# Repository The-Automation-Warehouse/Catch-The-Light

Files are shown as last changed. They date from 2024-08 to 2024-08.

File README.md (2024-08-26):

# Catch-The-Light

Made as part of Arcade Hack Club

Used github copilot when writing code and readme.

https://github.com/user-attachments/assets/25a0203d-37ab-4f56-9c1b-5fb8322b415e

Inspired by the arcade game [Speed Demon](https://www.arcade-museum.com/Arcade/speed-demon) I wanted to make crude version of it using a circular LED matrix I found ounline.

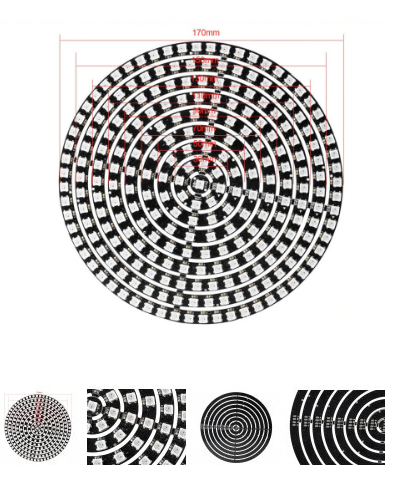
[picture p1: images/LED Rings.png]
Circular LED matrix


## Hardware

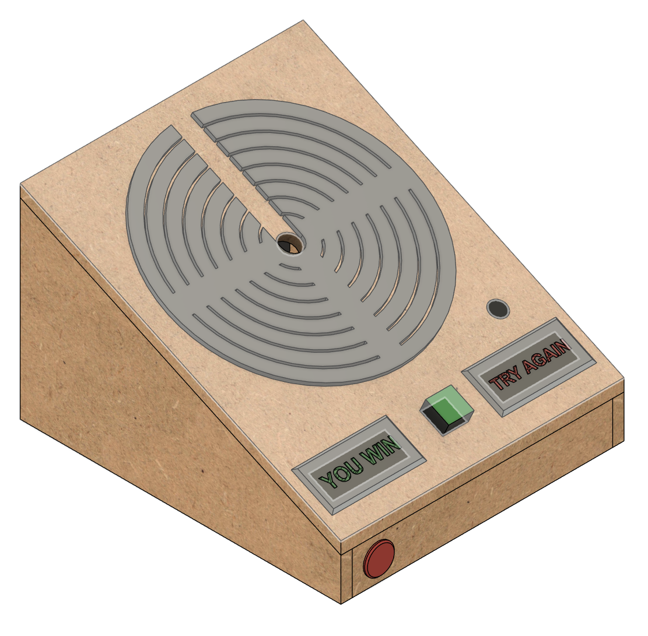
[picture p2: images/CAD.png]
CAD


I made a base out of 8mm MDF and used a 3D printed spacer to hold the LED rings.
This was not a very good design as MDF had a tendency to split and my paint job was not the best.

The stop button is a random button I found in my parts bin.
I also made two custom backlit signs for the game: green "YOU WIN" and red "TRY AGAIN".

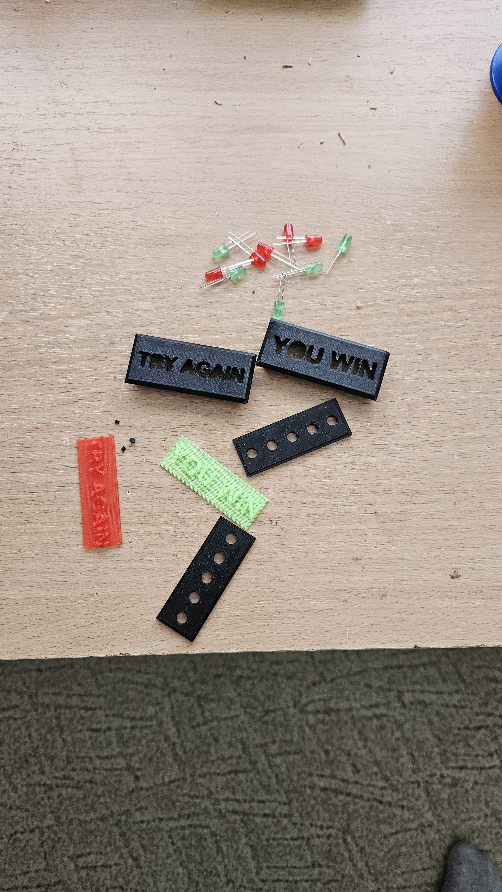
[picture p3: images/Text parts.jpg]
Text parts


The signs were printed in multiple parts and glued together (there is no need for a multi material printer).

A piezo buzzer is used for sound effects throughout the game.

The whole build is powered by a 5V 3A meanwell power supply with a switch mounted in the front and a C13 power socket in the back.

The brains of the operation is an arduino nano clone on piece of perfboard.

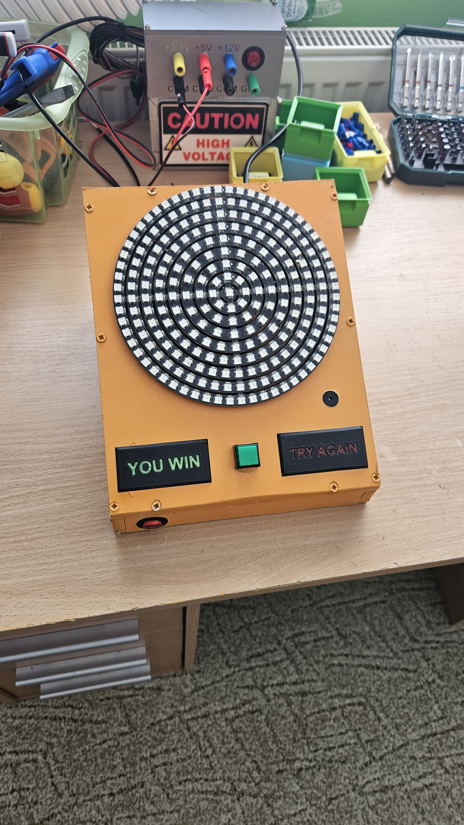
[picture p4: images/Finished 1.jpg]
Finished project image

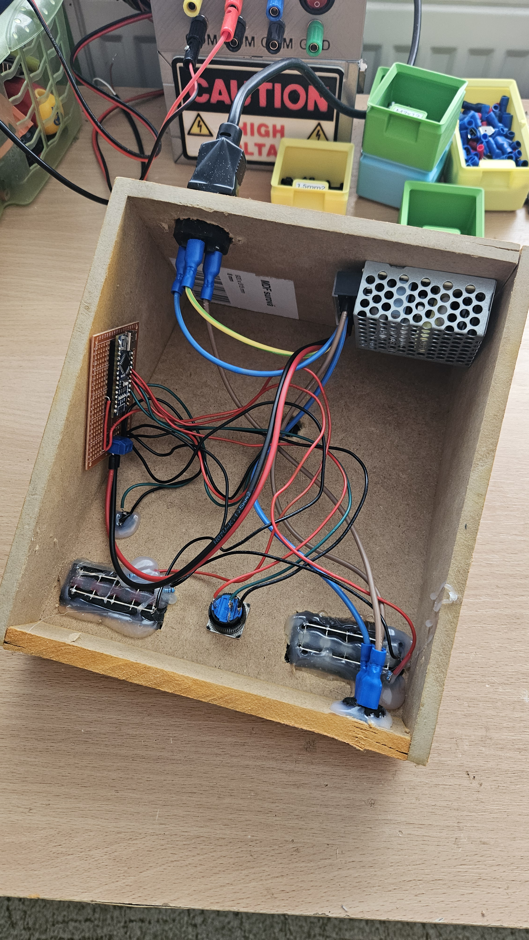
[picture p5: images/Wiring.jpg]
Wiring


## Shematic

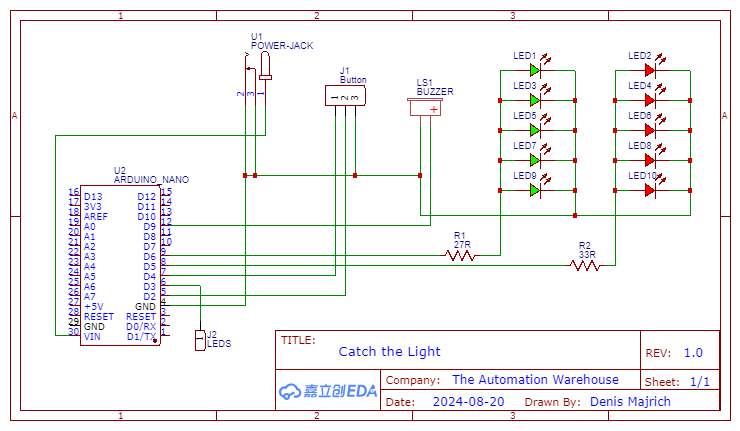
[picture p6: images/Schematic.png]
Schematic


## Code

The game starts with the player selecting of 3 difficulty levels, which changes how many LEDs are lit as the target (5, 4 or 3).
A light will start moving around the ring and the player has to press the button when the light is on any of the target LEDs.
If the player fails an animation will play and the game will restart.
If the player succeeds, the light will be able to move to the next ring and the target will change.
If the player reaches the last ring, an animation will play and the game will restart.

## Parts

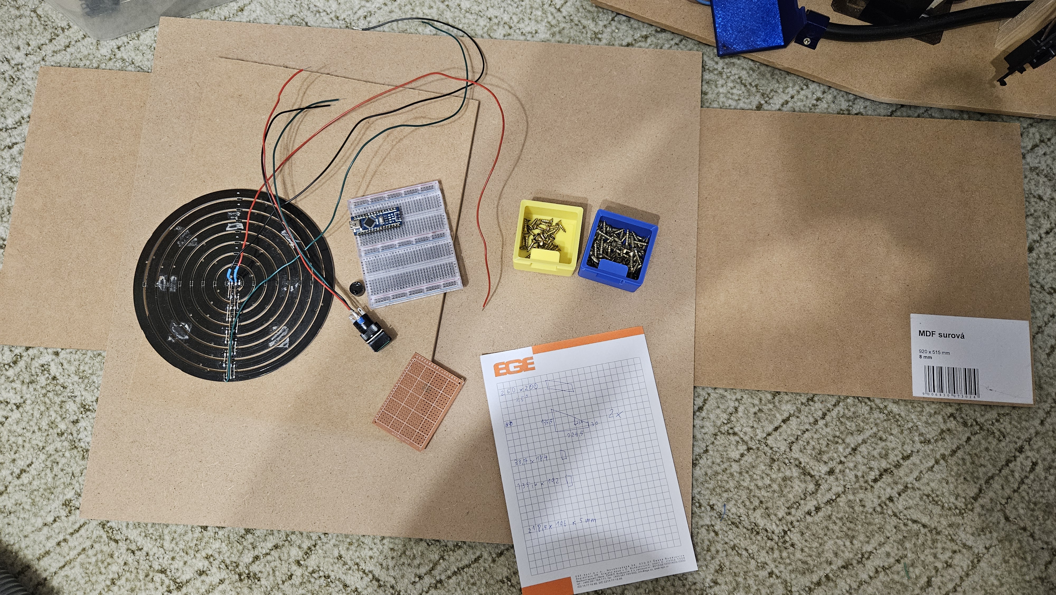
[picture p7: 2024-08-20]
making of/Parts.jpg

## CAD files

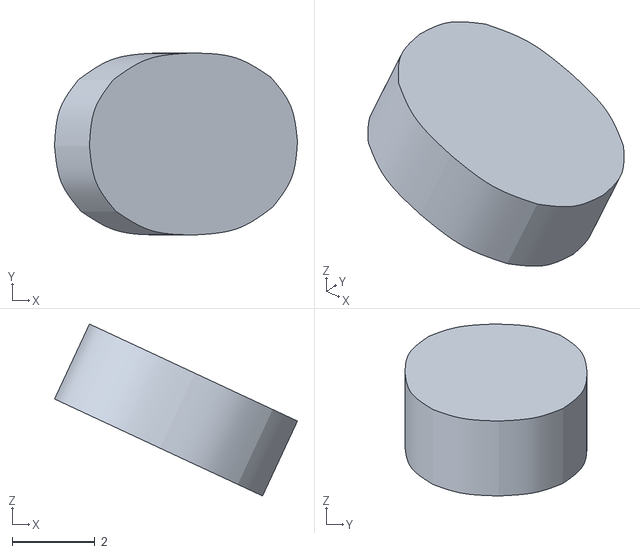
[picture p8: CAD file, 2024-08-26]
CAD/You Win - O.stl
5.88 x 4.40 x 4.16

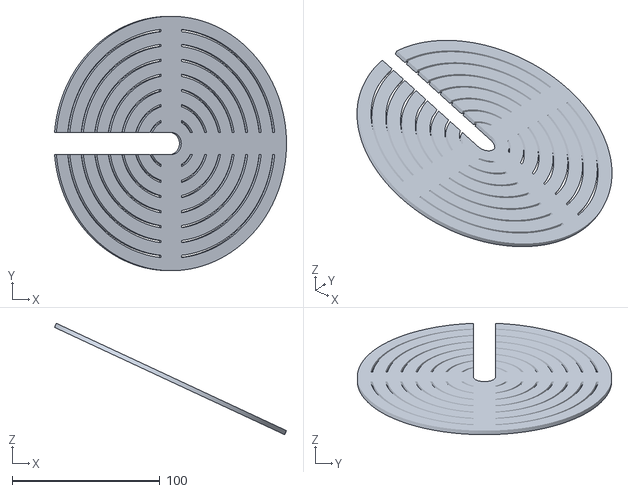
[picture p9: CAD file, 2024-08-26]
CAD/LED Rings Spacer.stl
156.8 x 172.0 x 75.3

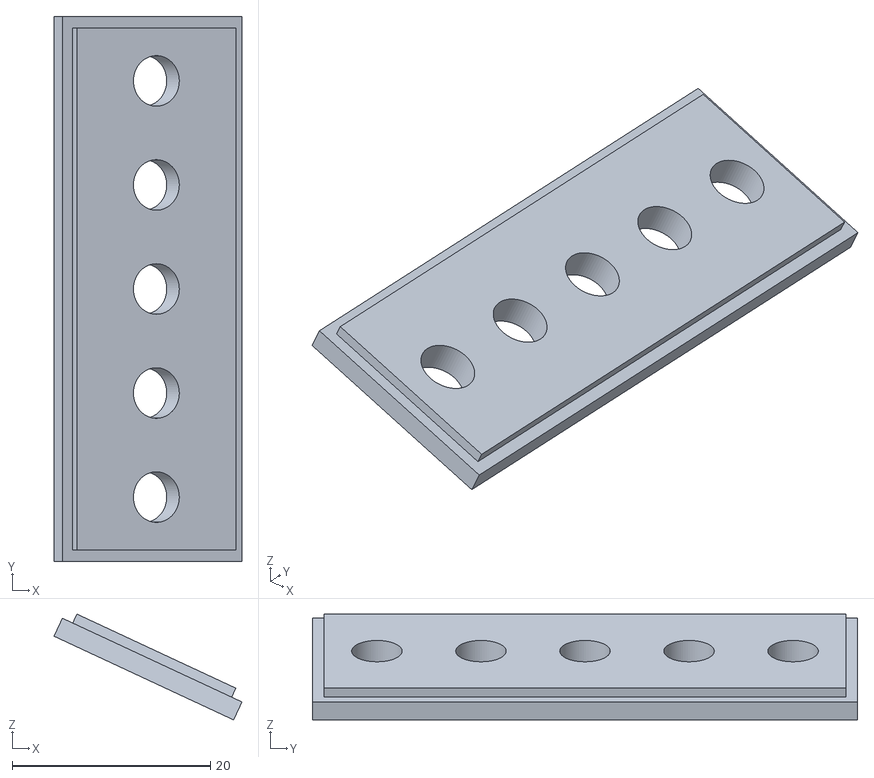
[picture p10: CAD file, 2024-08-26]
CAD/Try again - LED Holder.stl
19.0 x 55.0 x 10.7

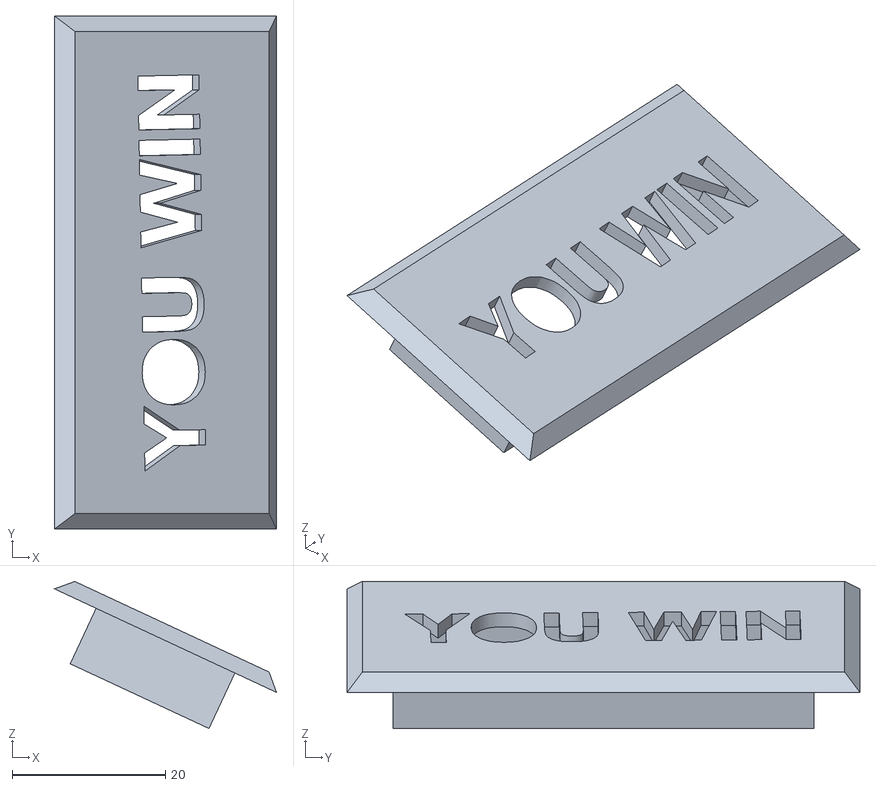
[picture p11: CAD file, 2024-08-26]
CAD/You Win - Cover.stl
29.0 x 67.0 x 19.2

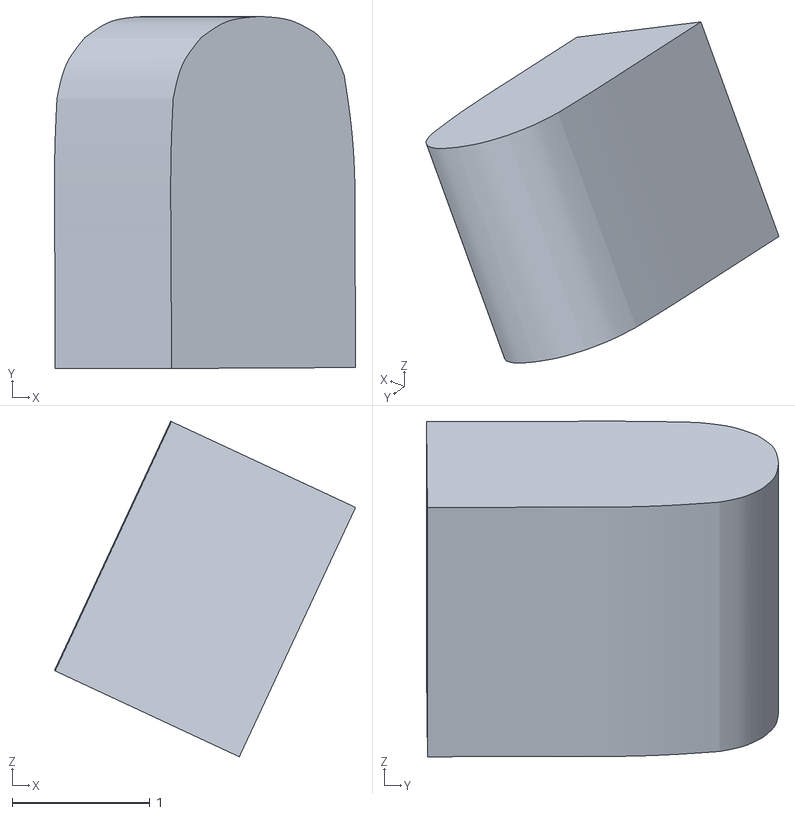
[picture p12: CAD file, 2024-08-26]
CAD/Try again - R.stl
2.19 x 2.56 x 2.44

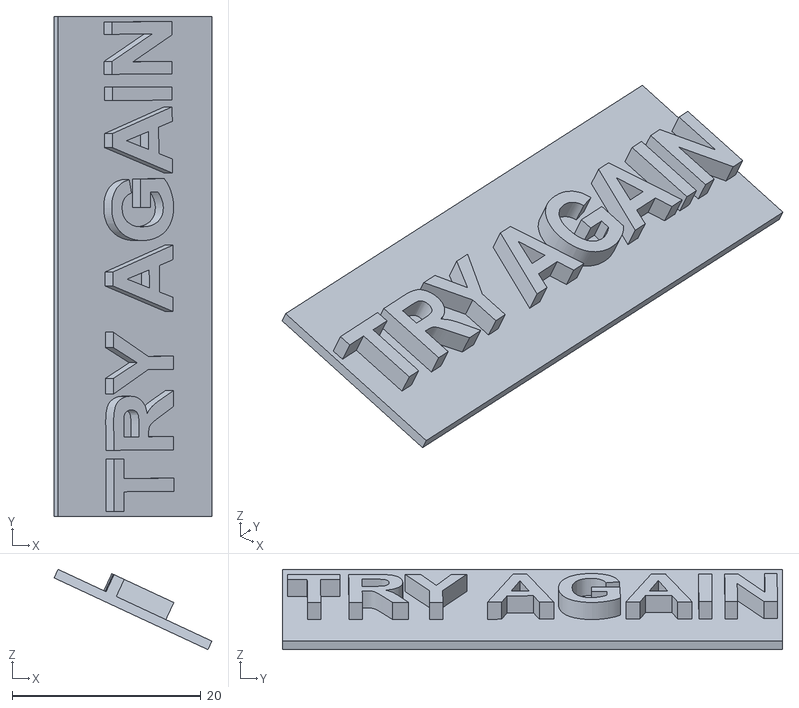
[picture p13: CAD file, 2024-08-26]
CAD/Try again - Text.stl
16.7 x 53.0 x 8.51

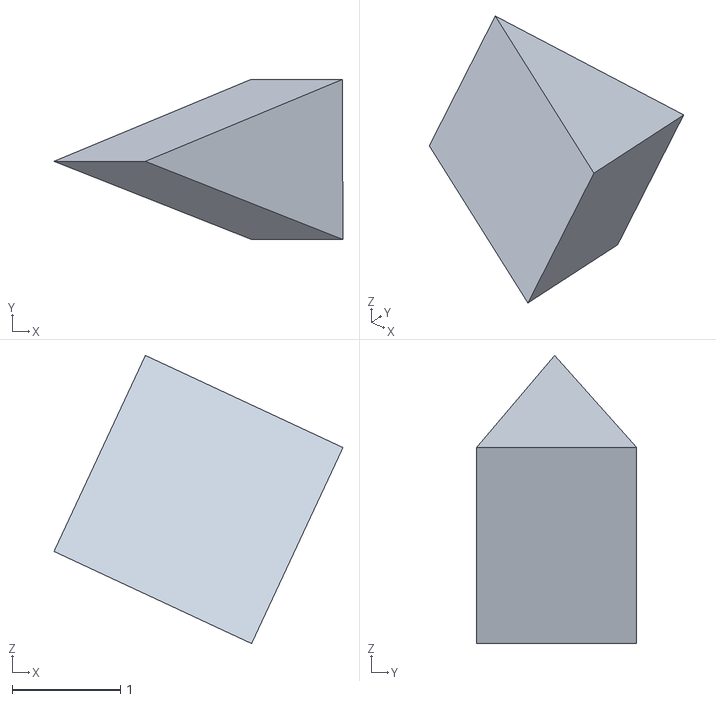
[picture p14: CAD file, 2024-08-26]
CAD/2x Try Again - A.stl
2.67 x 1.48 x 2.66

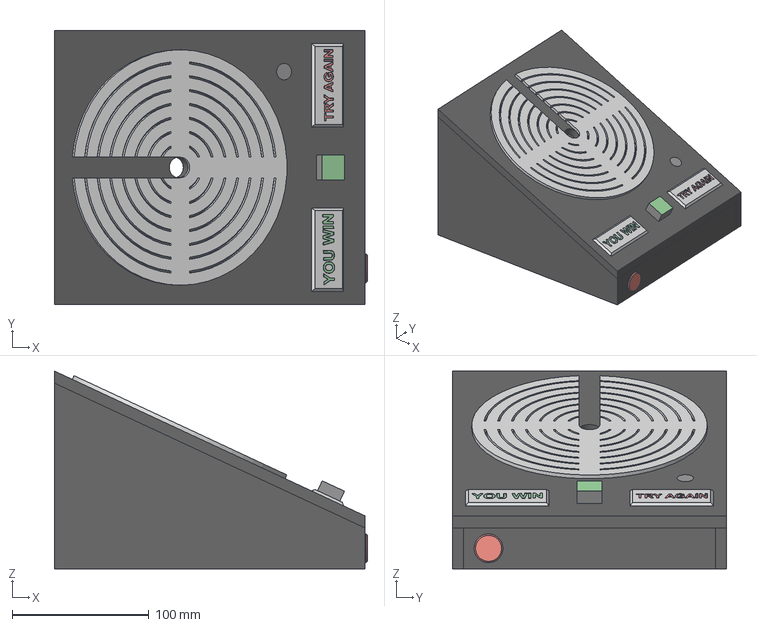
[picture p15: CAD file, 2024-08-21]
CAD/Catch The Light.step
228.6 x 200.0 x 144.5 mm

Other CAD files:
CAD/You Win - LED Holder.stl
CAD/You Win - Text.stl
CAD/Try again - Case.stl
CAD/Catch The Light.3mf
CAD/Catch The Light.f3d

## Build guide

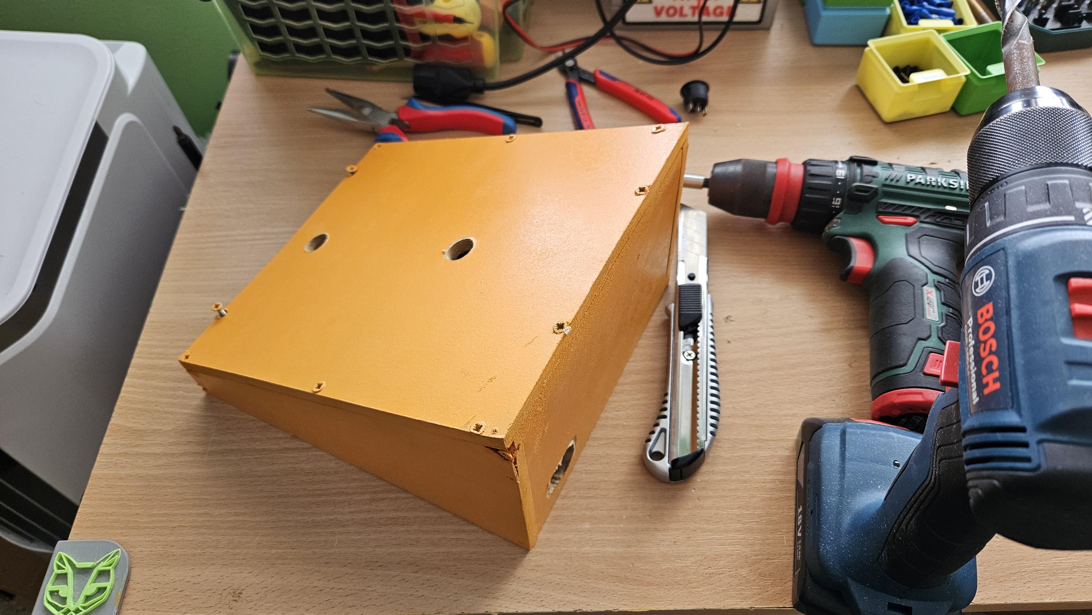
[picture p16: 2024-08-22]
making of/Holes.jpg

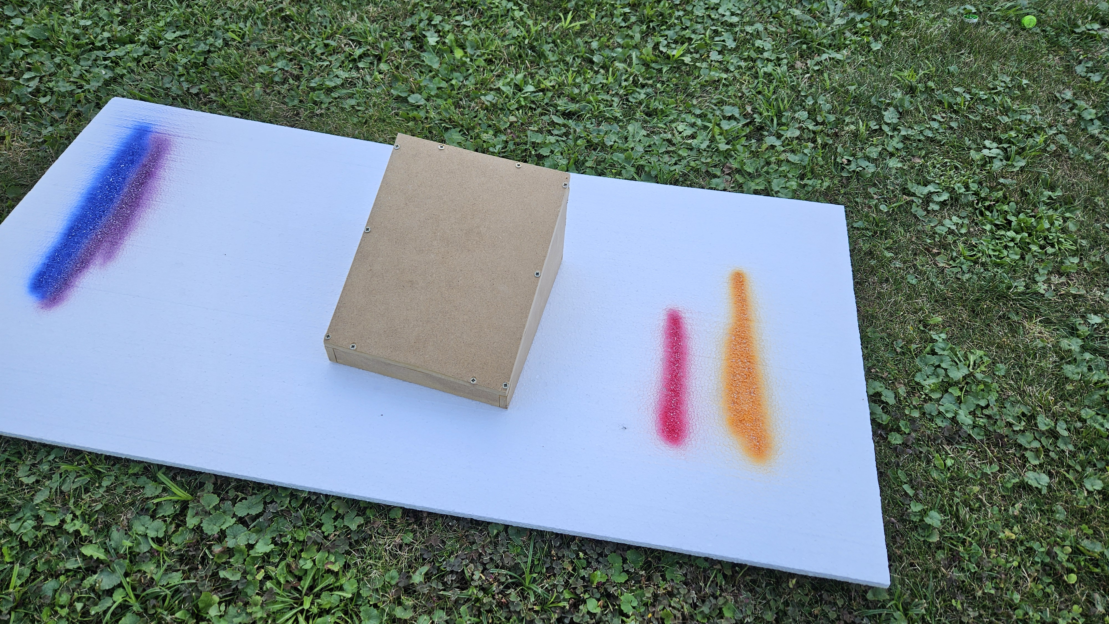
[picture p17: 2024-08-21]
making of/Woodworking 2.jpg

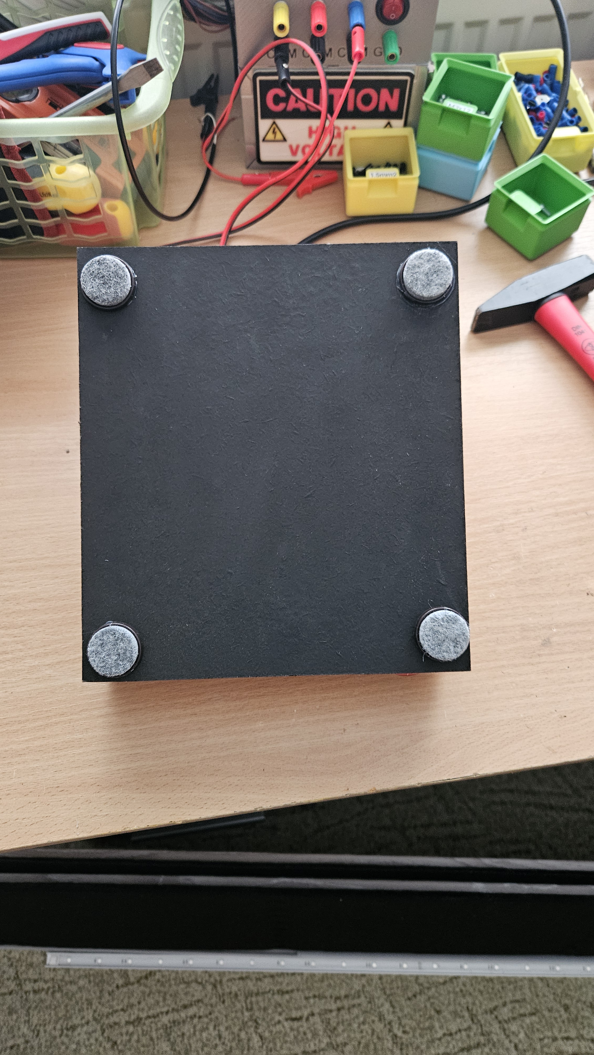
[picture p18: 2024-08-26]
making of/Feet 2.jpg

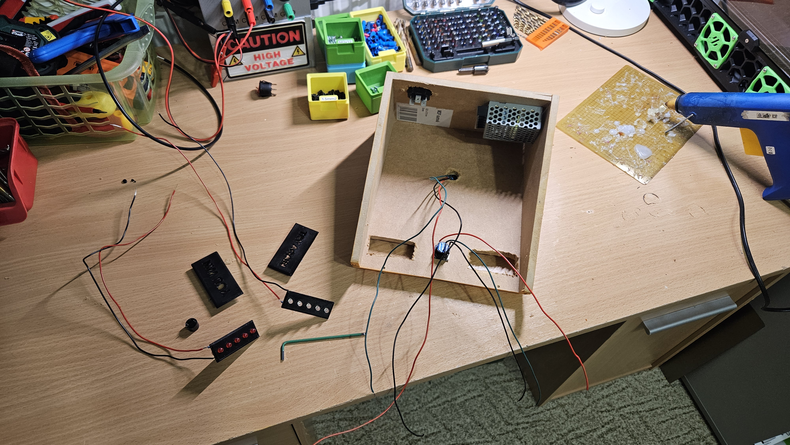
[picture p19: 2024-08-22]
making of/PSU mounted.jpg

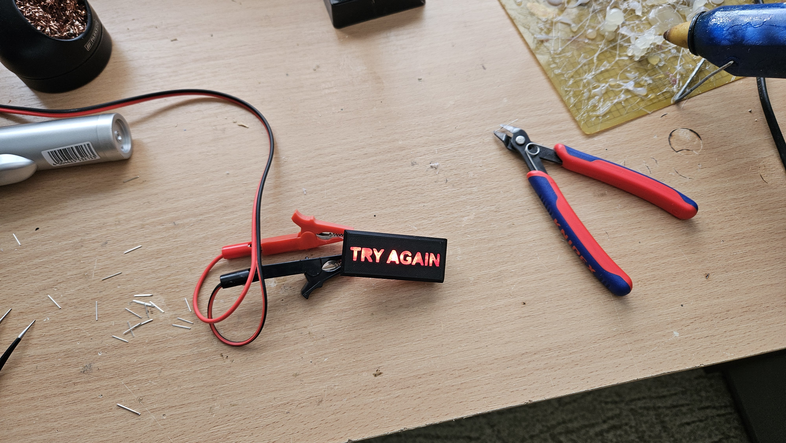
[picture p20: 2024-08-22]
making of/Text front.jpg

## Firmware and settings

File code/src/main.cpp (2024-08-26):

/*
 * Catch-The-Light
 * This is a crude arcade game inspired by "Speed Demon".
  * It consists of a ring of LEDs through which a light travels.
  * In each round, the light travels through the ring and the player has to press a button at the right time to stop the light.
  * The difficulty of the game changes the number of target LEDs that light up in each ring.
  * If the player presses the button at the right time, the light progresses to the next round and the next ring of LEDs lights up.
  * If the player presses the button at the wrong time, the game is over.
  * The game is won when the light has traveled through all the rings.
  * There are two backlit signs that light up when the game is won or lost.
 */



#include <Arduino.h>
#include <FastLED.h>

#define BUTTON 2
#define LEDS_PIN 3
#define BUTTON_LED 4
#define BUZZER 9
#define WIN_LEDS 6
#define TRY_AGAIN_LEDS 5

// Ring 1 - 60 LEDs
// Ring 2 - 48 LEDs
// Ring 3 - 32 LEDs
// Ring 4 - 26 LEDs
// Ring 5 - 16 LEDs
// Ring 6 - 12 LEDs
// Ring 7 - 8 LEDs
// One LED in the middle

int ring0 = 60;
int ring1 = 48;
int ring2 = 40;
int ring3 = 32;
int ring4 = 24;
int ring5 = 16;
int ring6 = 12;
int ring7 = 8;
int middle = 1;
int rings[] = {ring0, ring1, ring2, ring3, ring4, ring5, ring6, ring7, middle};
#define NUM_RINGS 7
#define NUM_LEDS 241
CRGB leds[NUM_LEDS];

bool doInterrupt = false;

// Game variables
int currentRing = 0;
int currentLED = 0;
int stopLED = 0;
int targetLEDs[5] = {0, 0, 0, 0, 0};
int oldTargetLEDs[80] = {0}; // Stores the previous target LEDs so that they can be lit up again in the next rounds
int totalLEDs = 0;
bool nextRound = false;
bool gameWon = false;
bool gameOver = false;
// Easy - 1
// Medium - 2
// Hard - 3
int difficulty = 0;


void handleButton();
void selectDifficulty();
void fillRing(CRGB leds[], CRGB color, int ringSizes[], int ringIndex);
void playGame();

void setup() { 

  Serial.begin(115200);
  pinMode(BUTTON, INPUT_PULLUP);
  pinMode(BUTTON_LED, OUTPUT);
  pinMode(BUZZER, OUTPUT);
  pinMode(WIN_LEDS, OUTPUT);
  pinMode(TRY_AGAIN_LEDS, OUTPUT);
  digitalWrite(WIN_LEDS, HIGH);
  digitalWrite(TRY_AGAIN_LEDS, HIGH);
  digitalWrite(BUTTON_LED, LOW);
  digitalWrite(BUZZER, LOW);

  randomSeed(analogRead(A0));

  FastLED.addLeds<WS2812B, LEDS_PIN, GRB>(leds, NUM_LEDS);
  FastLED.setBrightness(20);


  // Beep 4 times
  for (int i = 0; i < 5; i++) {
    tone(BUZZER, 480, 100);
    delay(200);
  }

  for (int i = 0; i < NUM_LEDS; i++) {
    fadeToBlackBy(leds, NUM_LEDS, 10);
    leds[i] = CRGB::Cyan;
    FastLED.show();
    delay(6);
  }

  digitalWrite(WIN_LEDS, LOW);
  digitalWrite(TRY_AGAIN_LEDS, LOW);

}





void loop() { 

  

  selectDifficulty();
  Serial.println("Difficulty selected: ");
  Serial.println(difficulty);
  playGame();


}






void handleButton() {

  if (doInterrupt) {
    stopLED = currentLED;
    // Check if the button is pressed at the right time (the stopLED is any of the targetLEDs)
    if (stopLED == targetLEDs[0] || stopLED == targetLEDs[1] || stopLED == targetLEDs[2] || stopLED == targetLEDs[3] || stopLED == targetLEDs[4]) {
      // If the button is pressed at the right time, the light progresses to the next ring
      if (currentRing == NUM_RINGS) {
        Serial.println("Game won!");
        gameOver = true;
        gameWon = true;
        doInterrupt = false;
      } else {
        currentRing++;
        nextRound = true;
        doInterrupt = false;
      }
    } else {
      // If the button is pressed at the wrong time, the game is over
      Serial.println("Game over!");
      gameOver = true;
      nextRound = true;
      doInterrupt = false;
    }
    Serial.print("Stopped at: ");
    Serial.println(stopLED);
  }

}








void selectDifficulty() {
  // The user can switch between the difficulty levels by pressing the button
  // The difficulty changes how many LEDs light up in each ring
  // By holding the button for 1 seconds, the user can confirm the selection
  
  // Easy - 1
  // Medium - 2
  // Hard - 3
  
  bool confirmSelection = false;
  bool changeDifficulty = false;
  difficulty = 1;
  unsigned long startMillis = millis(); // Store the start time
  const unsigned long timeout = 60000;  // 60 seconds timeout

  fill_solid(leds, NUM_LEDS, CRGB::Black);
  fillRing(leds, CRGB::Green, rings, 0);
  fillRing(leds, CRGB::Green, rings, 1);
  FastLED.show();

  digitalWrite(BUTTON_LED, HIGH);
  
  while (!confirmSelection && (millis() - startMillis < timeout)) {  // Add timeout condition
    if (digitalRead(BUTTON) == LOW) {
      delay(50); // Debounce delay
      if (digitalRead(BUTTON) == LOW) { // Check again after debounce delay
        unsigned long lastMillis = millis();
        // Check if the button is pressed for 1 second
        while (digitalRead(BUTTON) == LOW) {
          if (millis() - lastMillis > 1000) {
            confirmSelection = true;
            tone(BUZZER, 480, 400);
            break;
          }
        }
        if (!confirmSelection) {
          tone(BUZZER, 800, 100);
          changeDifficulty = true;
        }
      }
    }     
    
    if (changeDifficulty) {
      difficulty++;
      if (difficulty > 3) {
        difficulty = 1;
      }
      
      switch (difficulty) {
        case 1:
          fill_solid(leds, NUM_LEDS, CRGB::Black);
          fillRing(leds, CRGB::Green, rings, 0);
          fillRing(leds, CRGB::Green, rings, 1);
          FastLED.show();
          break;
        case 2:
          fill_solid(leds, NUM_LEDS, CRGB::Black);
          fillRing(leds, CRGB::Yellow, rings, 2);
          fillRing(leds, CRGB::Yellow, rings, 3);
          FastLED.show();
          break;
        case 3:
          fill_solid(leds, NUM_LEDS, CRGB::Black);
          fillRing(leds, CRGB::Red, rings, 4);
          fillRing(leds, CRGB::Red, rings, 5);
          FastLED.show();
          break;
      }
      changeDifficulty = false;
    }
  }

  digitalWrite(BUTTON_LED, LOW);
  fill_solid(leds, NUM_LEDS, CRGB::Black);
  delay(500);
  
  if (confirmSelection) {  // Only blink if selection is confirmed
    // Blink the corresponding ring to indicate the selected difficulty
    for (int i = 0; i < 3; i++) {
      switch (difficulty) {
        case 1:
          fillRing(leds, CRGB::Green, rings, 0);
          fillRing(leds, CRGB::Green, rings, 1);
          break;
        case 2:
          fillRing(leds, CRGB::Yellow, rings, 2);
          fillRing(leds, CRGB::Yellow, rings, 3);
          break;
        case 3:
          fillRing(leds, CRGB::Red, rings, 4);
          fillRing(leds, CRGB::Red, rings, 5);
          break;
      }
      FastLED.show();
      delay(200);
      fill_solid(leds, NUM_LEDS, CRGB::Black);
      FastLED.show();
      delay(200);
    }
  } else {
    // If the selection is not confirmed run the function again
    selectDifficulty();
  }
}

  






void fillRing(CRGB leds[], CRGB color, int ringSizes[], int ringIndex) {
    int tottalLeds = 0;
    for (int i = 0; i < ringIndex+1; i++) {
        tottalLeds += ringSizes[i];
    }
    
  for (int i = tottalLeds - ringSizes[ringIndex]; i < tottalLeds; i++) {
    leds[i] = color;
  }
}












  

void playGame() {
  while (!gameOver)
  {
    if (gameOver) {
      break;
    }
    Serial.print("Current ring: ");
    Serial.println(currentRing);
    totalLEDs = 0;
    currentLED = 0;
    FastLED.show();
    // Pick a random LED to light up as the target depending on the difficulty
    // Easy - 5 LED
    // Medium - 4 LEDs
    // Hard - 3 LEDs

resetTarget:

    for (int j = 0; j < currentRing; j++) {
      totalLEDs += rings[j];
    }
    targetLEDs[0] = random(totalLEDs, totalLEDs + rings[currentRing]);

    switch (difficulty) {
      case 1:
      {
        Serial.println("Easy");
        targetLEDs[1] = targetLEDs[0] + 1;
        targetLEDs[2] = targetLEDs[0] + 2;
        targetLEDs[3] = targetLEDs[0] - 1;
        targetLEDs[4] = targetLEDs[0] - 2;
      }
        break;
      case 2:
      {
        Serial.println("Medium");
        targetLEDs[1] = targetLEDs[0] + 1;
        targetLEDs[2] = targetLEDs[0] + 2;
        targetLEDs[3] = targetLEDs[0] - 1;
      }
        break; 
      case 3:
      {
        Serial.println("Hard");
        targetLEDs[1] = targetLEDs[0] + 1;
        targetLEDs[2] = targetLEDs[0] - 1;
      }
        break;
      }

      // Print the target LEDs
      Serial.print("Target LEDs: ");
      for (int j = 0; j < 5; j++) {
        Serial.print(targetLEDs[j]);
        Serial.print(" ");
      }
      Serial.println();

      // Print the old target LEDs
      Serial.print("Old target LEDs: ");
      for (int j = 0; j < 50; j++) {
        Serial.print(oldTargetLEDs[j]);
        Serial.print(" ");
      }
      Serial.println();
      // Check if the target LEDs are not out of bounds
      for (int j = 0; j < 5; j++) {
        if (targetLEDs[j] != 0) {
          if (targetLEDs[j] < totalLEDs || targetLEDs[j] + 1 > totalLEDs + rings[currentRing]) {
            for (int j = 0; j < 5; j++) {
              targetLEDs[j] = 0;
            }
            totalLEDs = 0;
            Serial.println("Target out of bounds");
            randomSeed(analogRead(A0));
            goto resetTarget;
          }
        }
      }


      // Light up the target LEDs
      for (int j = 0; j < 5; j++) {
        if (targetLEDs[j] != 0) {
          leds[targetLEDs[j]] = CHSV(64, 255, 128);
        }
      }
      FastLED.show();
      delay(30);
      attachInterrupt(digitalPinToInterrupt(BUTTON), handleButton, FALLING);
      delay(20);
      doInterrupt = true;
      while (!nextRound && !gameOver) {
        // Play the actual game

        // Adjust the fade speed depending on the current ring but cap it at 160
        fadeToBlackBy(leds, NUM_LEDS, min(160, (currentRing + 1) * 25));
        
        // Light up the target LEDs with 70% brightness yellow additevly
        for (int j = 0; j < 5; j++) {
          if (targetLEDs[j] != 0) {
            // Get the current color of the LED and add yellow to it
            leds[targetLEDs[j]] = blend(leds[targetLEDs[j]], CHSV(64, 255, 178), 128);
          }
        }
        // Light up the old target LEDs with 70% brightness red additevly
        for (unsigned int j = 0; j < sizeof(oldTargetLEDs) / sizeof(oldTargetLEDs[0]); j++) {
            if (oldTargetLEDs[j] != 0) {
              leds[oldTargetLEDs[j]] = blend(leds[oldTargetLEDs[j]], CHSV(0, 255, 178), 128);
            }
        }
        // Draw the moving light
        // Change the color of the light depending on the ring (if its in the current ring or not)
        if (currentLED < totalLEDs) {
          leds[currentLED] = CRGB::Green;
          tone(BUZZER, 32);
          delayMicroseconds(700);
          noTone(BUZZER);
          delay(6);
        } else {
          leds[currentLED] = CRGB::Blue;
          tone(BUZZER, 32);
          delayMicroseconds(1200);
          noTone(BUZZER);
          delay(28);
        }
        FastLED.show();
        
        currentLED++;

        if (currentLED == totalLEDs + rings[currentRing]) {
          currentLED = totalLEDs;
        }
      }
      // Bling the stopLED
      for (int i = 0; i < 3; i++) {
        if (stopLED == targetLEDs[0] || stopLED == targetLEDs[1] || stopLED == targetLEDs[2] || stopLED == targetLEDs[3] || stopLED == targetLEDs[4]) {
          leds[stopLED] = CRGB::Purple;
        } else {
          leds[stopLED] = CRGB::Red;
        }
        FastLED.show();
        tone(BUZZER, 800, 80);
        delay(100);
        if (stopLED == targetLEDs[0] || stopLED == targetLEDs[1] || stopLED == targetLEDs[2] || stopLED == targetLEDs[3] || stopLED == targetLEDs[4]) {
          leds[stopLED] = CRGB::Yellow;
        } else {
          leds[stopLED] = CRGB::Black;
        }
        FastLED.show();
        tone(BUZZER, 800, 80);
        delay(100);
      }
      doInterrupt = false;
      detachInterrupt(digitalPinToInterrupt(BUTTON));
      nextRound = false;

      // Add the target LEDs to the old target LEDs so that they can be lit up again in the next rounds
      // The old target LEDs are stored in a array where each ring is given 10 spaces
      for (int j = 0; j < 5; j++) {
        if (targetLEDs[j] != 0) {
          oldTargetLEDs[currentRing * 10 + j] = targetLEDs[j];
        }
      }
  }
  Serial.println("Game over, playing animation");
  if (gameWon) {
    // Light up the win LEDs and play a winning sound and animation
    // The animation lights up every second LED in the ring and alternates odd and even LEDs
    for (int i = 0; i < 10; i++) {
      tone(BUZZER, 1200, 100);
      digitalWrite(WIN_LEDS, HIGH);
      fill_solid(leds, NUM_LEDS, CRGB::Black);
      for (int j = 0; j < NUM_LEDS/2; j++) {
        leds[j*2] = CRGB::Green;
      }
      FastLED.show();
      tone(BUZZER, 1200, 100);
      delay(100);
      tone(BUZZER, 1200, 100);
      delay(100);
      tone(BUZZER, 1200, 100);
      digitalWrite(WIN_LEDS, LOW);
      fill_solid(leds, NUM_LEDS, CRGB::Black);
      for (int j = 0; j < NUM_LEDS/2; j++) {
        leds[j*2+1] = CRGB::Green;
      }
      FastLED.show();
      delay(200);
    }


  } else {
    // Blink the try again LEDs and play and angry beeping sound
    for (int i = 0; i < 3; i++) {
      fill_solid(leds, NUM_LEDS, CRGB::Red);
      digitalWrite(TRY_AGAIN_LEDS, HIGH);
      FastLED.show();
      tone(BUZZER, 100, 200);
      delay(200);
      digitalWrite(TRY_AGAIN_LEDS, LOW);
      fill_solid(leds, NUM_LEDS, CRGB::Black);
      FastLED.show();
      delay(200);
    }
  }

  // Reset the game variables
  currentRing = 0;
  currentLED = 0;
  stopLED = 0;
  for (int j = 0; j < 5; j++) {
    targetLEDs[j] = 0;
  }
  for (int j = 0; j < 80; j++) {
    oldTargetLEDs[j] = 0;
  }
  nextRound = false;
  gameWon = false;
  gameOver = false;
  doInterrupt = false;
  
  // Play the loading animation
  for (int i = 0; i < NUM_LEDS; i++) {
    fadeToBlackBy(leds, NUM_LEDS, 10);
    leds[i] = CRGB::Cyan;
    FastLED.show();
    delay(6);
  }
}

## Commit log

2024-08-19 Create Catch The Light.step
    [Catch The Light.step]
2024-08-19 Added the schematic
    [Catch The Light.step]
2024-08-20 Change of plan
    [Catch The Light.step]
2024-08-21 Update Catch The Light.step
    [Catch The Light.step]
2024-08-22 Added drilling photos
2024-08-22 Create Remaking leds.jpg
2024-08-22 Create PSU mounted.jpg
2024-08-23 Create Wiring 1.jpg
2024-08-23 Create Wiring 2.jpg
2024-08-26 Added CAD files and update README.md
    [2x Try Again - A.stl, Catch The Light.3mf, Catch The Light.f3d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]
